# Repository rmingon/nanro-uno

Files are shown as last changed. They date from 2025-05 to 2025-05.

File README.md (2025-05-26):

# ATmega88PA Sensor Interface Board

This project is a compact microcontroller development board based on the **ATmega88PA**, equipped with an **MPU-6050** accelerometer/gyroscope and USB interface. It is designed for embedded systems development, particularly in motion-sensing or robotics applications.

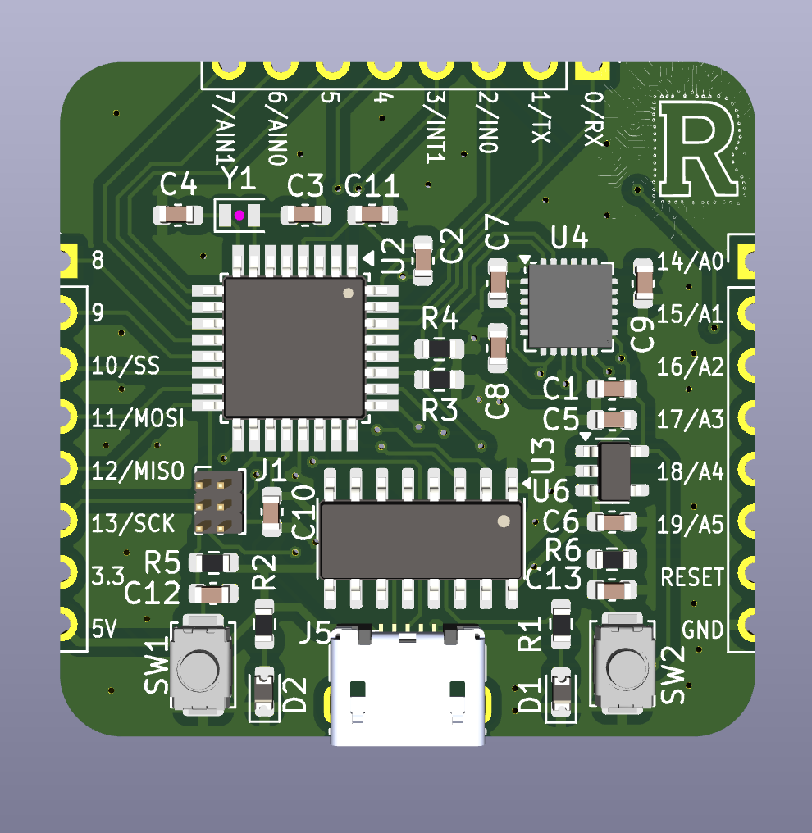
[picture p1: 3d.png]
3d


## Features

- **Microcontroller**: ATmega88PA (TQFP32)
- **IMU Sensor**: MPU-6050 (3-axis gyroscope + 3-axis accelerometer)
- **USB Interface**: CH340C USB-to-Serial converter
- **Onboard Voltage Regulation**: 5V to 3.3V via AP2112K-3.3
- **USB Power and Data via Micro-USB**
- **External Programming Header (ISP)**
- **I2C and UART breakout pins**
- **Reset and User Button**
- **LED Indicators**: Power and status/debug
- **Crystal Oscillator**: 8 MHz external crystal
- **Compact, breadboard-friendly form factor**

---

## Schematic Overview

- **Power Supply**:
  - Micro-USB supplies +5V.
  - LDO (AP2112K-3.3) regulates down to +3.3V for MPU-6050 and I/O.
- **Microcontroller (U2)**: ATmega88PA is the central controller.
  - Interfaces: I2C (SCL/SDA), UART (TX/RX), and SPI (MISO/MOSI/SCK)
  - Reset circuitry via pushbutton and capacitor.
- **MPU-6050 (U4)**: Connected via I2C with 4.7kΩ pull-ups.
- **USB to Serial (U3 - CH340C)**:
  - Used for serial communication and programming via UART.
- **ISP Header (J1)**: For initial bootloader flashing or full firmware flashing.

---

## PCB Details

- **2-layer PCB** with top and bottom copper planes.
- Carefully routed signal traces with decoupling capacitors close to ICs.
- Exposed pads for easy pin access to GPIOs.
- Mounting holes and labeled pin headers.
- Silkscreen labeling of pin functions for ease of use.
- 3D Render available for visualization and placement inspection.

---

## Pinout Summary

| Pin | Function | Notes |
|-----|---|---|
| PB0–PB7 | GPIO / UART / SPI | Digital I/O and communication |
| PC0–PC5 | GPIO / I2C | Includes SDA/SCL for MPU6050 |
| PD0–PD7 | GPIO / UART | TX/RX, user-defined GPIO |
| SW1 | Reset Button | Pull-down with 10kΩ resistor |
| SW2 | User Button | Connected to PB0 |
| J1 | ISP Header | MISO/MOSI/SCK/RESET |

---

## Getting Started

### 1. Flashing Firmware

- **Via ISP (J1)**: Use AVR ISP programmer.
- **Via UART (CH340C)**: Use bootloader (if pre-installed).

### 2. Power Supply

- Plug in via **Micro-USB**.
- Onboard LDO provides 3.3V logic supply.

### 3. I2C Communication

- MPU-6050 is accessible at default I2C address `0x68`.
- Ensure pull-ups (R3, R4 = 4.7kΩ) are present on SDA/SCL lines.

---

## Tools Used

- **Schematic & PCB Design**: [KiCad EDA](https://kicad.org)
- **Microcontroller Programming**: `avrdude`, `Arduino as ISP`, PlatformIO
- **Firmware Development**: C/C++ (AVR-GCC or Arduino IDE)

---

## License

Open-source hardware. You may use, modify, and distribute under the terms of the  MIT license.

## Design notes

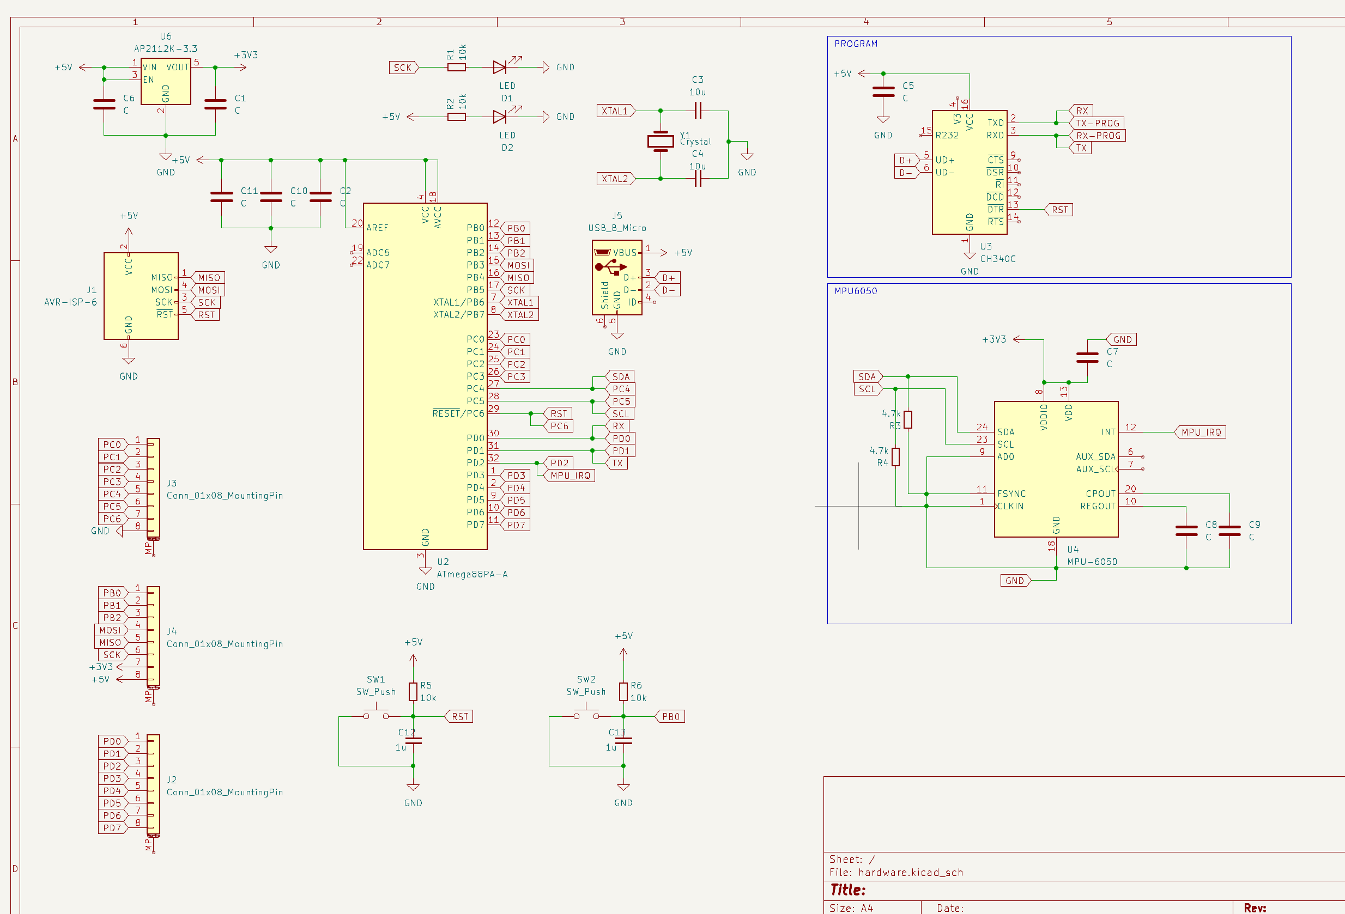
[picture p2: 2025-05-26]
schematic.png

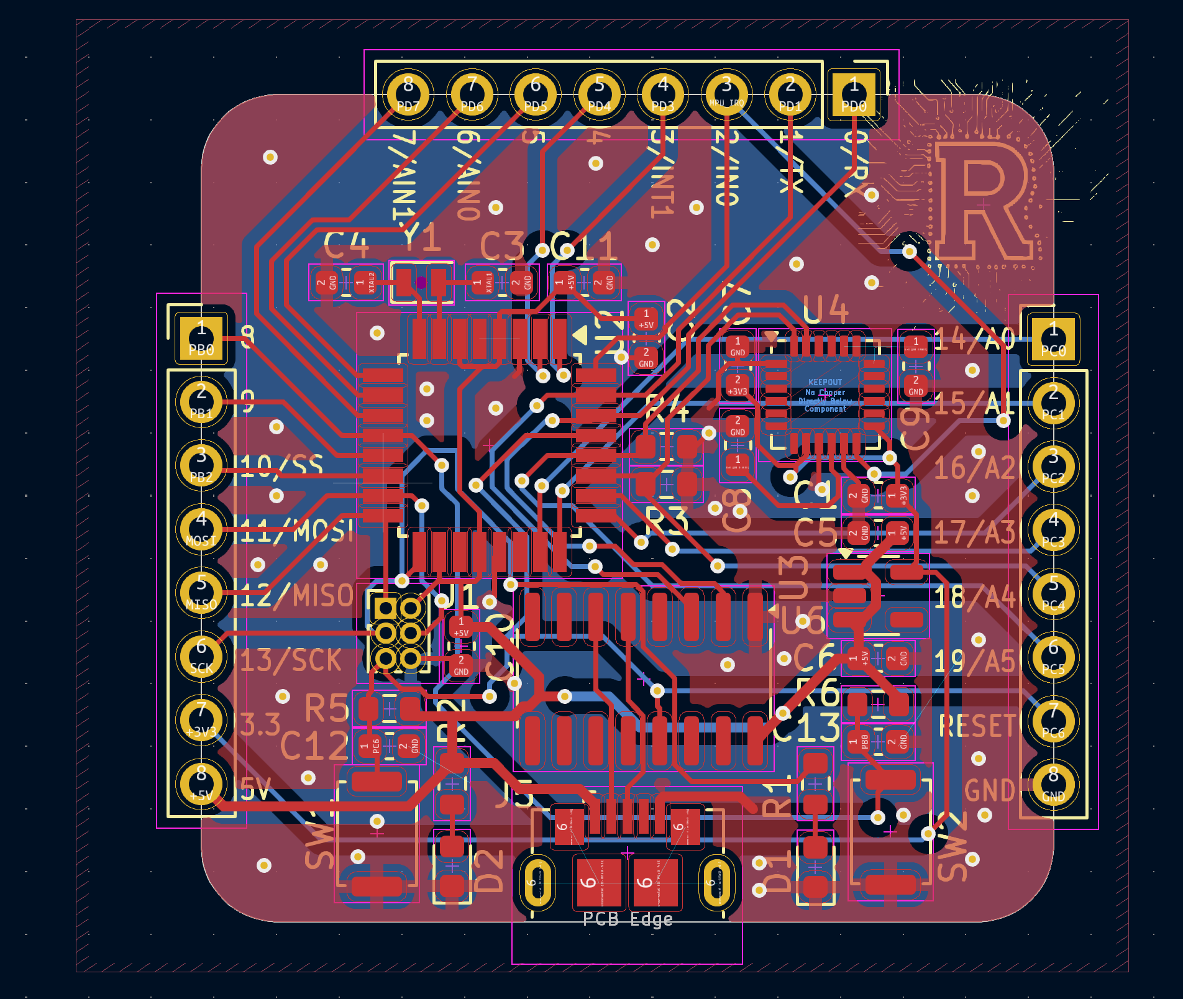
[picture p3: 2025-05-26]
pcb.png

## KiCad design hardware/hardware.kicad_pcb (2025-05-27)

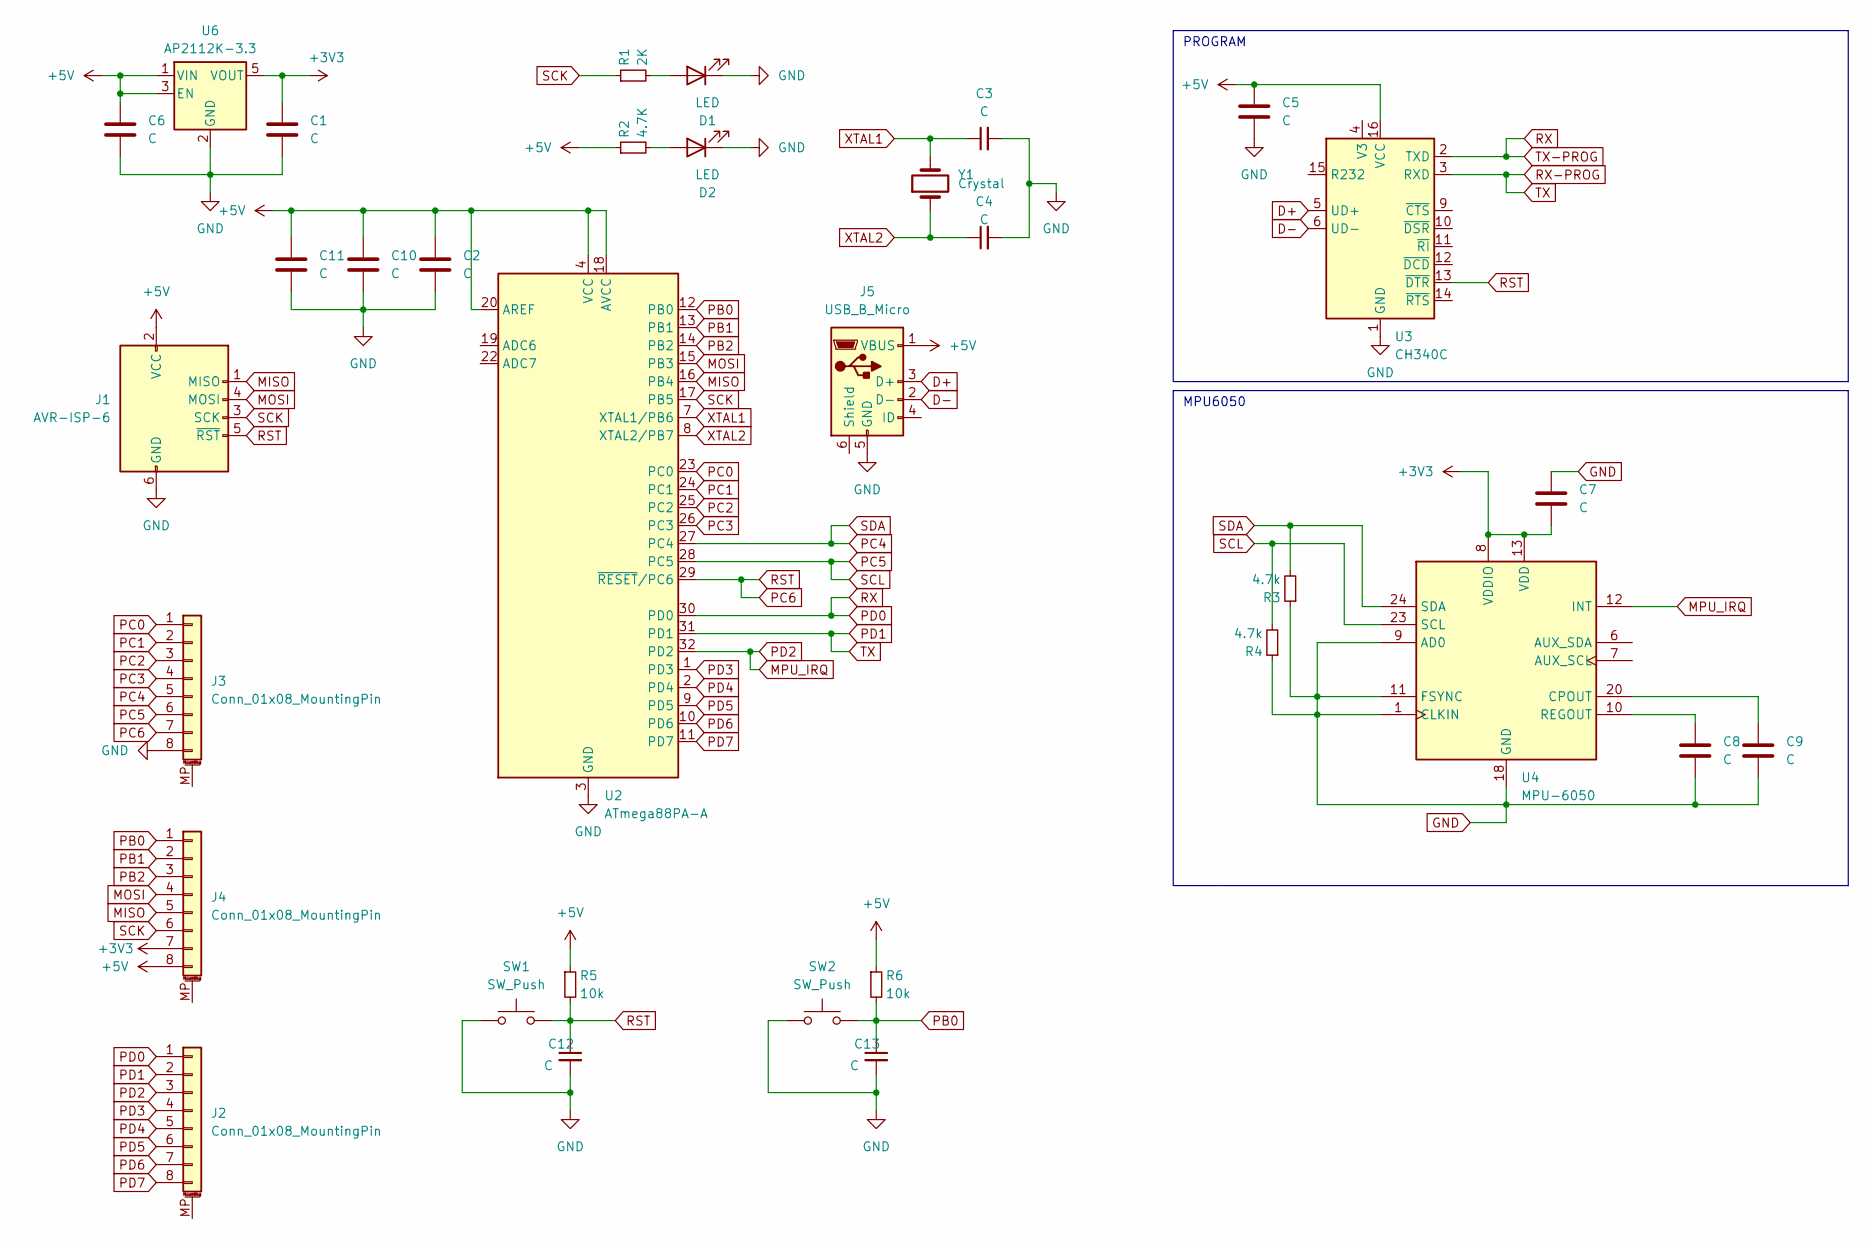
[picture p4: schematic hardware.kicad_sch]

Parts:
C1, C6, C10: C; C_0603_1608Metric; LCSC C14858
C2, C7, C11, C12, C13: C; C_0603_1608Metric; LCSC C5137611
C3, C4, C5: C; C_0603_1608Metric; LCSC C106245
C8: C; C_0603_1608Metric; LCSC C1322361
C9: C; C_0603_1608Metric; LCSC C1604
D1: LED; D_0603_1608Metric; LCSC C965799
D2: LED; D_0603_1608Metric; LCSC C965807
J1: AVR-ISP-6; PinHeader_2x03_P1.00mm_Vertical
J2, J3, J4: Conn_01x08_MountingPin; PinHeader_1x08_P2.54mm_Vertical
J5: USB_B_Micro; USB_Micro-B_GCT_USB3076-30-A; LCSC C6007475
R1: 2K; R_0603_1608Metric; LCSC C22975
R2: 4.7K; R_0603_1608Metric; LCSC C99782
R3, R4: 4.7k; R_0603_1608Metric; LCSC C99782
R5, R6: 10k; R_0603_1608Metric; LCSC C2930027
SW1, SW2: SW_Push; SW_Push_SPST_NO_Alps_SKRK; LCSC C115357
U2: ATmega88PA-A; TQFP-32_7x7mm_P0.8mm; LCSC C8727
U3: CH340C; SOIC-16_3.9x9.9mm_P1.27mm; LCSC C84681
U4: MPU-6050; InvenSense_QFN-24_4x4mm_P0.5mm; LCSC C24112
U6: AP2112K-3.3; SOT-23-5; LCSC C51118
Y1: Crystal; Crystal_SMD_3225-4Pin_3.2x2.5mm; LCSC C2682775

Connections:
+3V3: C1.1, C7.2, J4.7, U4.8 (VDDIO), U4.13 (VDD), U6.5 (VOUT)
+5V: C2.1, C5.1, C6.1, C10.1, C11.1, J1.2 (VCC), J4.8, J5.1 (VBUS), R2.1, R5.1, R6.1, U2.4 (VCC), U2.6 (VCC), U2.18 (AVCC), U2.20 (AREF), U3.16 (VCC), U6.1 (VIN), U6.3 (EN)
D+: J5.3 (D+), U3.5 (UD+)
D-: J5.2 (D-), U3.6 (UD-)
GND: C1.2, C2.2, C3.2, C4.2, C5.2, C6.2, C7.1, C8.2, C9.2, C10.2, C11.2, C12.2, C13.2, D1.1 (K), D2.1 (K), J1.6 (GND), J3.8, J5.5 (GND), R3.1, R4.1, SW1.1, SW2.1, U2.3 (GND), U2.5 (GND), U2.21 (GND), U3.1 (GND), U4.1 (CLKIN), U4.9 (AD0), U4.11 (FSYNC), U4.18 (GND), U6.2 (GND)
MISO: J1.1 (MISO), J4.5, U2.16 (PB4)
MOSI: J1.4 (MOSI), J4.4, U2.15 (PB3)
MPU_IRQ: J2.3, U2.32 (PD2), U4.12 (INT)
unnamed: D1.2 (A), R1.2
unnamed: D2.2 (A), R2.2
unnamed: C9.1, U4.20 (CPOUT)
unnamed: C8.1, U4.10 (REGOUT)
PB0: C13.1, J4.1, R6.2, SW2.2, U2.12 (PB0)
PB1: J4.2, U2.13 (PB1)
PB2: J4.3, U2.14 (PB2)
PC0: J3.1, U2.23 (PC0)
PC1: J3.2, U2.24 (PC1)
PC2: J3.3, U2.25 (PC2)
PC3: J3.4, U2.26 (PC3)
PC4: J3.5, R3.2, U2.27 (PC4), U4.24 (SDA)
PC5: J3.6, R4.2, U2.28 (PC5), U4.23 (SCL)
PC6: C12.1, J1.5 (~RST), J3.7, R5.2, SW1.2, U2.29 (~RESET/PC6), U3.13 (~DTR)
PD0: J2.1, U2.30 (PD0), U3.2 (TXD)
PD1: J2.2, U2.31 (PD1), U3.3 (RXD)
PD3: J2.4, U2.1 (PD3)
PD4: J2.5, U2.2 (PD4)
PD5: J2.6, U2.9 (PD5)
PD6: J2.7, U2.10 (PD6)
PD7: J2.8, U2.11 (PD7)
SCK: J1.3 (SCK), J4.6, R1.1, U2.17 (PB5)
XTAL1: C3.1, U2.7 (XTAL1/PB6), Y1.2
XTAL2: C4.1, U2.8 (XTAL2/PB7), Y1.1

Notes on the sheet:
MPU6050
PROGRAM

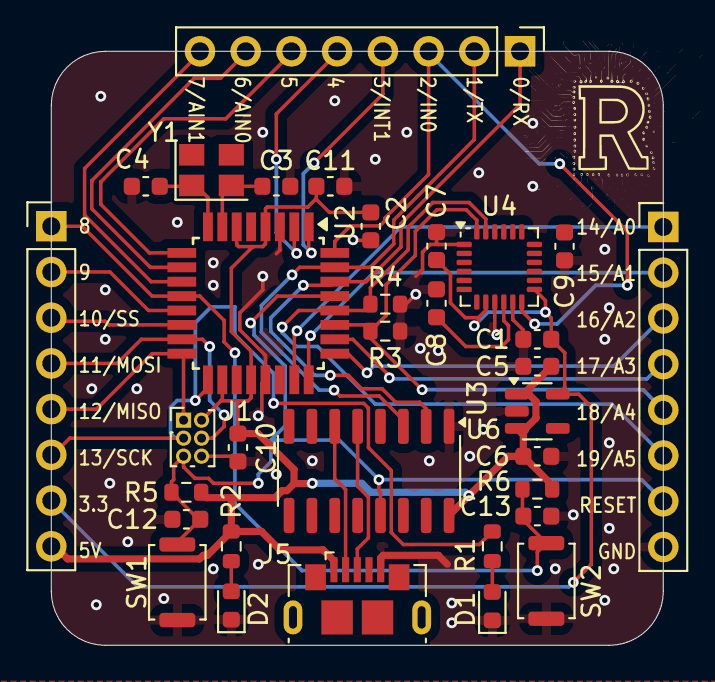
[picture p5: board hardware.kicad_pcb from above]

Board: 2 copper layers, 34.0 x 33.0 mm, 33 parts (0 on the bottom side), 32 nets.

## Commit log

2025-05-26 finish wiring
    [hardware.kicad_pcb, hardware.kicad_sch]
2025-05-26 update parts lcsc
    [hardware.kicad_pcb, hardware.kicad_sch]
2025-05-27 fix user button capacitor ground
    [hardware.kicad_pcb]
